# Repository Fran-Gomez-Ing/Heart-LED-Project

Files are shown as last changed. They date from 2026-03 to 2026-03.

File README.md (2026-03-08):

# Heart-LED-Project
Heart-shaped LED badge with integrated Li-ion battery charging system.

A self-initiated project to bridge the gap between theory and hardware. I designed, routed, and hand-assembled this PCB from scratch. It’s a portable, rechargeable system featuring:

Power: Portable system featuring a Li-ion battery with an integrated charging circuit (TP4056).

Architecture: Discrete LED array driven by an NE555 timer on a custom-shaped, double-layer PCB.

Toolchain: KiCad 9.0.

What I Learned:

End-to-End Workflow: Moved from theory to a physical product by managing the full cycle: footprints, BOM, and Gerber generation for manufacturing.

Component Selection: Mastered reading datasheets to select appropriate ICs, like the TP4056 for charging and the NE555 timer for logic.

DFA (Design for Assembly): Implemented HandSolder footprints with enlarged pads to ensure reliable manual assembly and easier debugging.

Power Integration: Gained practical experience with Li-ion battery management and USB power standards.

Possible Improvements:

Battery Safety: V1.0 focuses on the charging cycle. In the next iteration, I will add a DW01A protection IC and 8205A MOSFETs to prevent undervoltage (below 2.4V) and ensure battery longevity.

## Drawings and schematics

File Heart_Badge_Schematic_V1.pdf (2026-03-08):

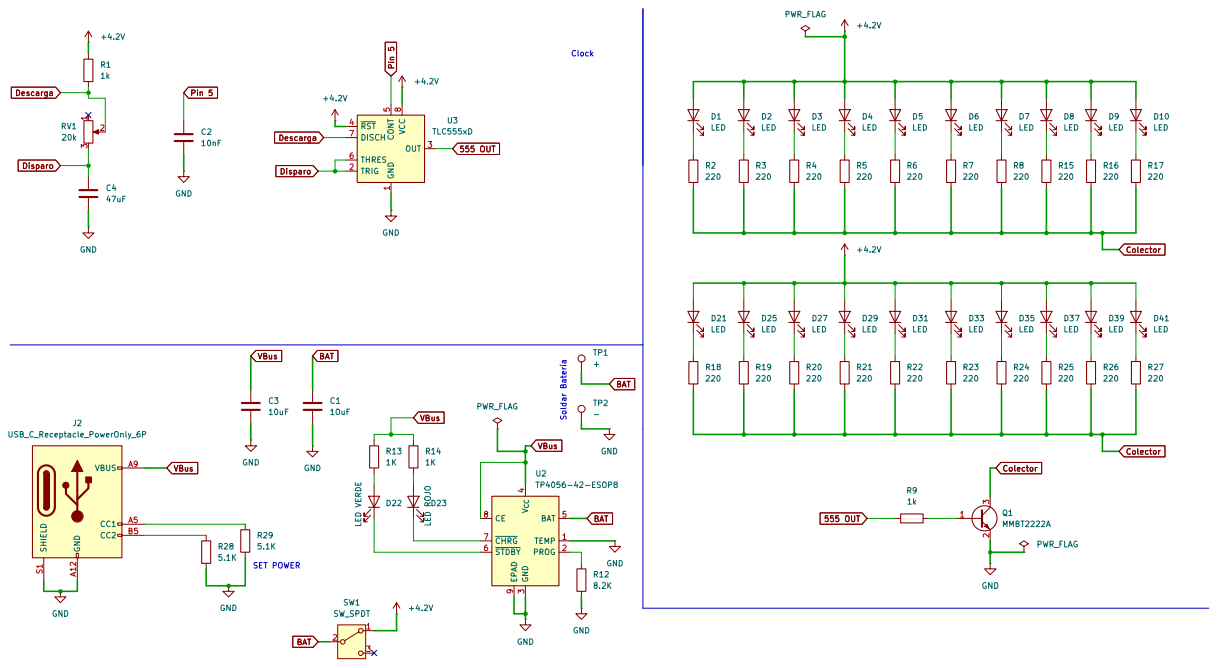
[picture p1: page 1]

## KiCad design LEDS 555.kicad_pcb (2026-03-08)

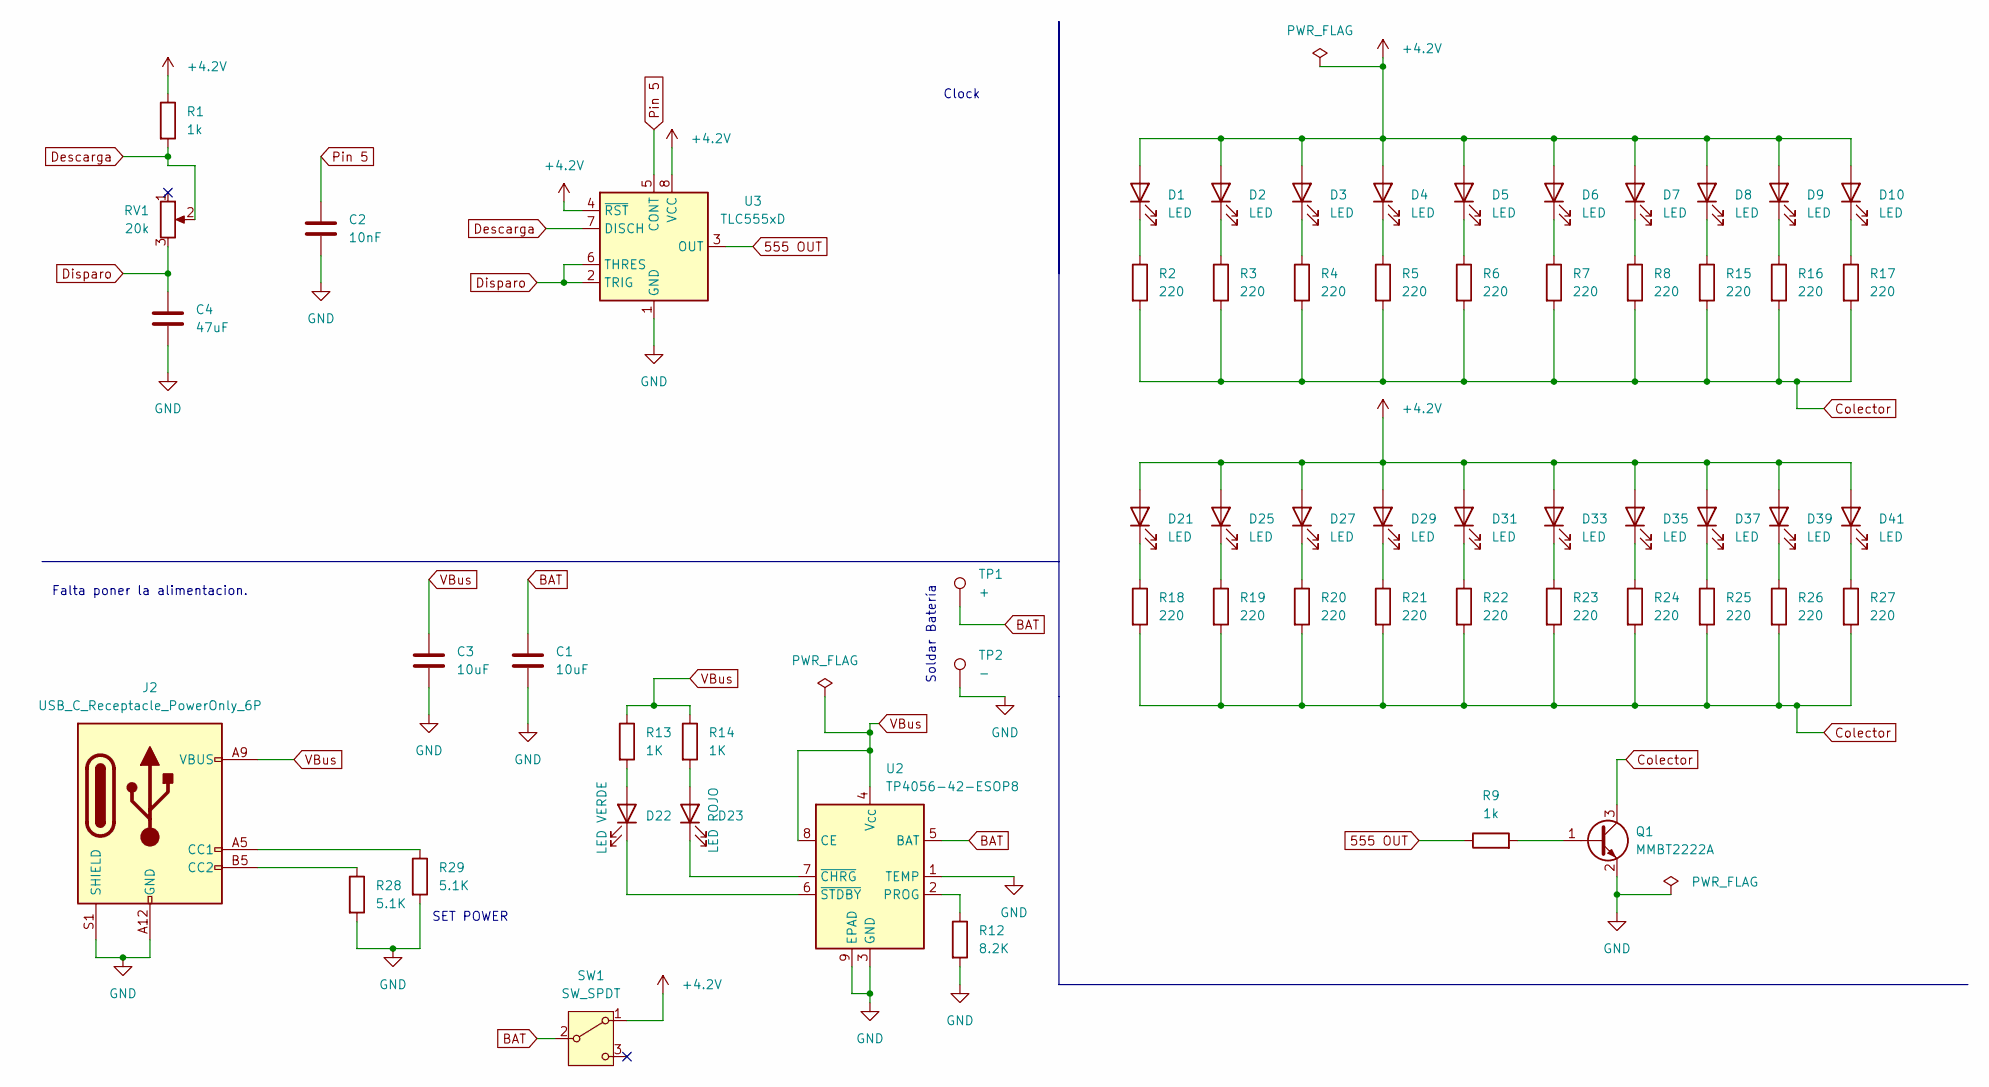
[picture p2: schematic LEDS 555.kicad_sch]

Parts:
C1, C3: 10uF; C_0805_2012Metric_Pad1.18x1.45mm_HandSolder; LCSC C440198
C2: 10nF; C_0805_2012Metric_Pad1.18x1.45mm_HandSolder; LCSC C83170
C4: 47uF; C_0805_2012Metric_Pad1.18x1.45mm_HandSolder; LCSC C16780
D1, D2, D3, D4, D5, D6, D7, D8, D9, D10, D21, D25, D27, D29, D31, D33, D35, D37, D39, D41: LED; LED_D3.0mm; LCSC C2895492
D22: LED VERDE; LED_0805_2012Metric_Pad1.15x1.40mm_HandSolder; LCSC C25170728
D23: LED ROJO; LED_0805_2012Metric_Pad1.15x1.40mm_HandSolder; LCSC C19171391
J2: USB_C_Receptacle_PowerOnly_6P; USB_C_Receptacle_GCT_USB4135-GF-A_6P_TopMnt_Horizontal; LCSC C5438410
Q1: MMBT2222A; SOT-23; LCSC C82460
R1, R9: 1k; R_0805_2012Metric_Pad1.20x1.40mm_HandSolder; LCSC C17513
R2, R3, R4, R5, R6, R7, R8, R15, R16, R17, R18, R19, R20, R21, R22, R23, R24, R25, R26, R27: 220; R_0805_2012Metric_Pad1.20x1.40mm_HandSolder; LCSC C17557
R12: 8.2K; R_0805_2012Metric_Pad1.20x1.40mm_HandSolder; LCSC C17828
R13, R14: 1K; R_0805_2012Metric_Pad1.20x1.40mm_HandSolder; LCSC C17513
R28, R29: 5.1K; R_0805_2012Metric_Pad1.20x1.40mm_HandSolder; LCSC C27834
RV1: 20k; Potentiometer_Alps_RK09K_Single_Vertical; LCSC C470290
SW1: SW_SPDT; SW_SPDT_PCM12; LCSC C221841
TP1: +; TestPoint_Pad_D2.0mm
TP2: -; TestPoint_Pad_D2.0mm
U2: TP4056-42-ESOP8; SOIC-8-1EP_3.9x4.9mm_P1.27mm_EP2.41x3.3mm_ThermalVias; LCSC C16581
U3: TLC555xD; SOIC-8_3.9x4.9mm_P1.27mm; LCSC C6986

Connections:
555 OUT: R9.1, U3.3 (OUT)
+4.2V: D1.2 (A), D2.2 (A), D3.2 (A), D4.2 (A), D5.2 (A), D6.2 (A), D7.2 (A), D8.2 (A), D9.2 (A), D10.2 (A), D21.2 (A), D25.2 (A), D27.2 (A), D29.2 (A), D31.2 (A), D33.2 (A), D35.2 (A), D37.2 (A), D39.2 (A), D41.2 (A), R1.1, SW1.1 (A), U3.4 (~RST), U3.8 (VCC)
BAT: C1.1, SW1.2 (B), TP1.1, U2.5 (BAT)
Colector: Q1.3 (C), R2.2, R3.2, R4.2, R5.2, R6.2, R7.2, R8.2, R15.2, R16.2, R17.2, R18.2, R19.2, R20.2, R21.2, R22.2, R23.2, R24.2, R25.2, R26.2, R27.2
Descarga: R1.2, RV1.2, U3.7 (DISCH)
Disparo: C4.1, RV1.3, U3.2 (TRIG), U3.6 (THRES)
GND: C1.2, C2.2, C3.2, C4.2, J2.A12 (GND), J2.B12 (GND), J2.S1 (SHIELD), Q1.2 (E), R12.2, R28.2, R29.2, TP2.1, U2.1 (TEMP), U2.3 (GND), U2.9 (EPAD), U3.1 (GND)
unnamed: D1.1 (K), R2.1
unnamed: D2.1 (K), R3.1
unnamed: D3.1 (K), R4.1
unnamed: D4.1 (K), R5.1
unnamed: D5.1 (K), R6.1
unnamed: D6.1 (K), R7.1
unnamed: D7.1 (K), R8.1
unnamed: D8.1 (K), R15.1
unnamed: D9.1 (K), R16.1
unnamed: D10.1 (K), R17.1
unnamed: D21.1 (K), R18.1
unnamed: D22.2 (A), R13.2
unnamed: D22.1 (K), U2.6 (~STDBY)
unnamed: D23.2 (A), R14.2
unnamed: D23.1 (K), U2.7 (~CHRG)
unnamed: D25.1 (K), R19.1
unnamed: D27.1 (K), R20.1
unnamed: D29.1 (K), R21.1
unnamed: D31.1 (K), R22.1
unnamed: D33.1 (K), R23.1
unnamed: D35.1 (K), R24.1
unnamed: D37.1 (K), R25.1
unnamed: D39.1 (K), R26.1
unnamed: D41.1 (K), R27.1
unnamed: J2.A5 (CC1), R29.1
unnamed: J2.B5 (CC2), R28.1
unnamed: Q1.1 (B), R9.2
unnamed: R12.1, U2.2 (PROG)
Pin 5: C2.1, U3.5 (CONT)
VBus: C3.1, J2.A9 (VBUS), J2.B9 (VBUS), R13.1, R14.1, U2.4 (V_{CC}), U2.8 (CE)

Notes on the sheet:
Clock
Soldar Batería
SET POWER
Falta poner la alimentacion.

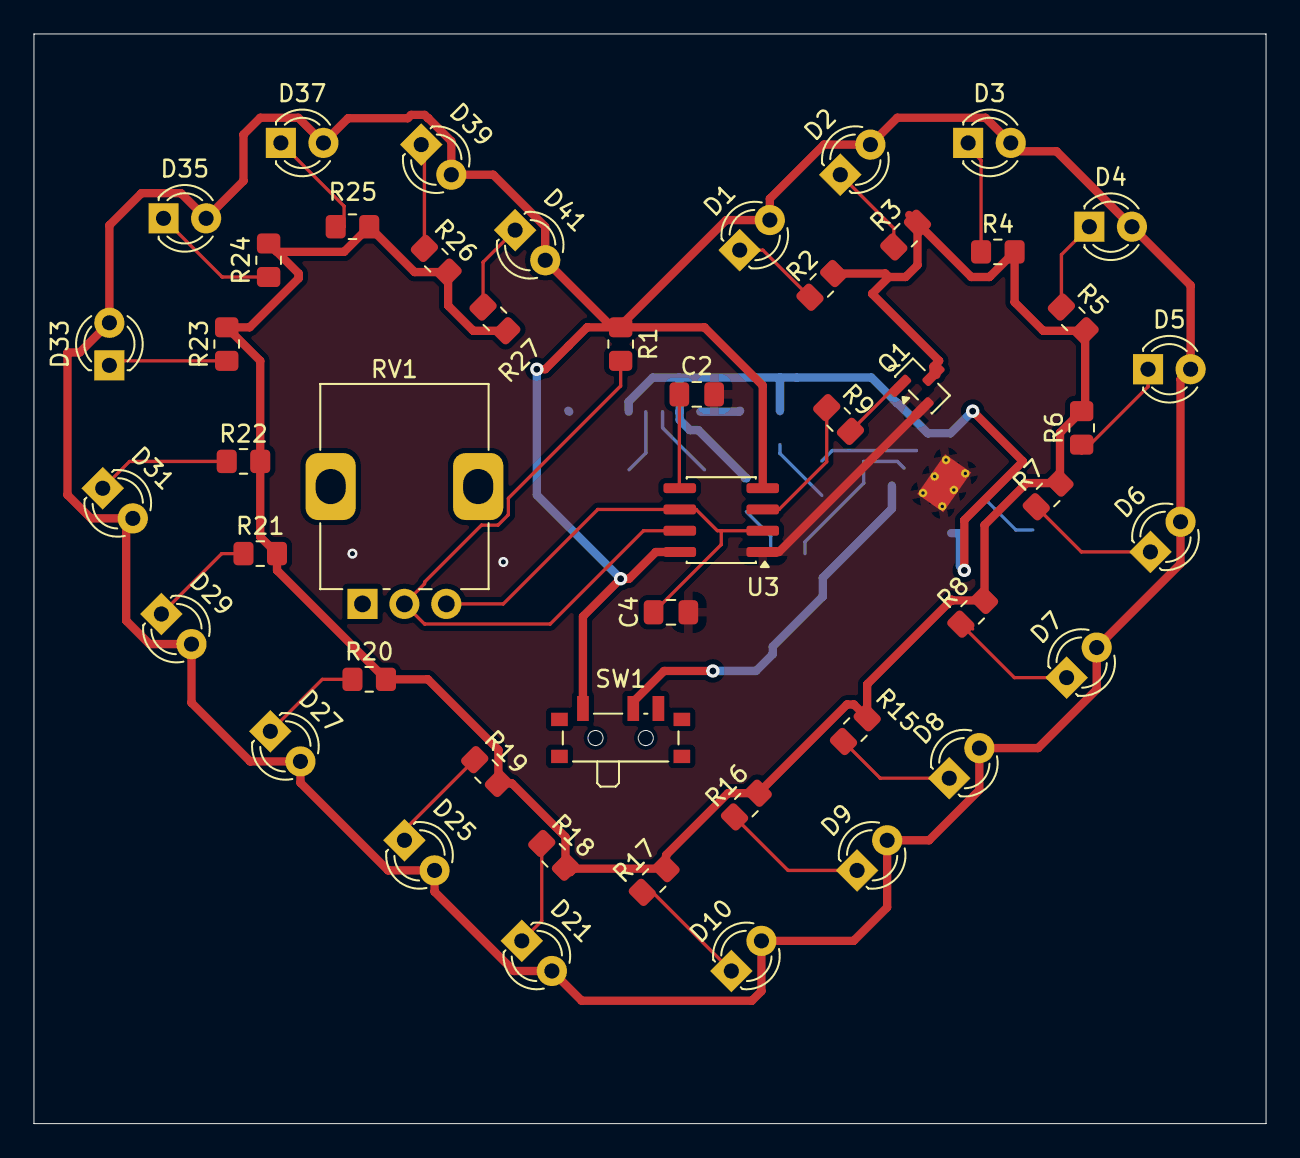
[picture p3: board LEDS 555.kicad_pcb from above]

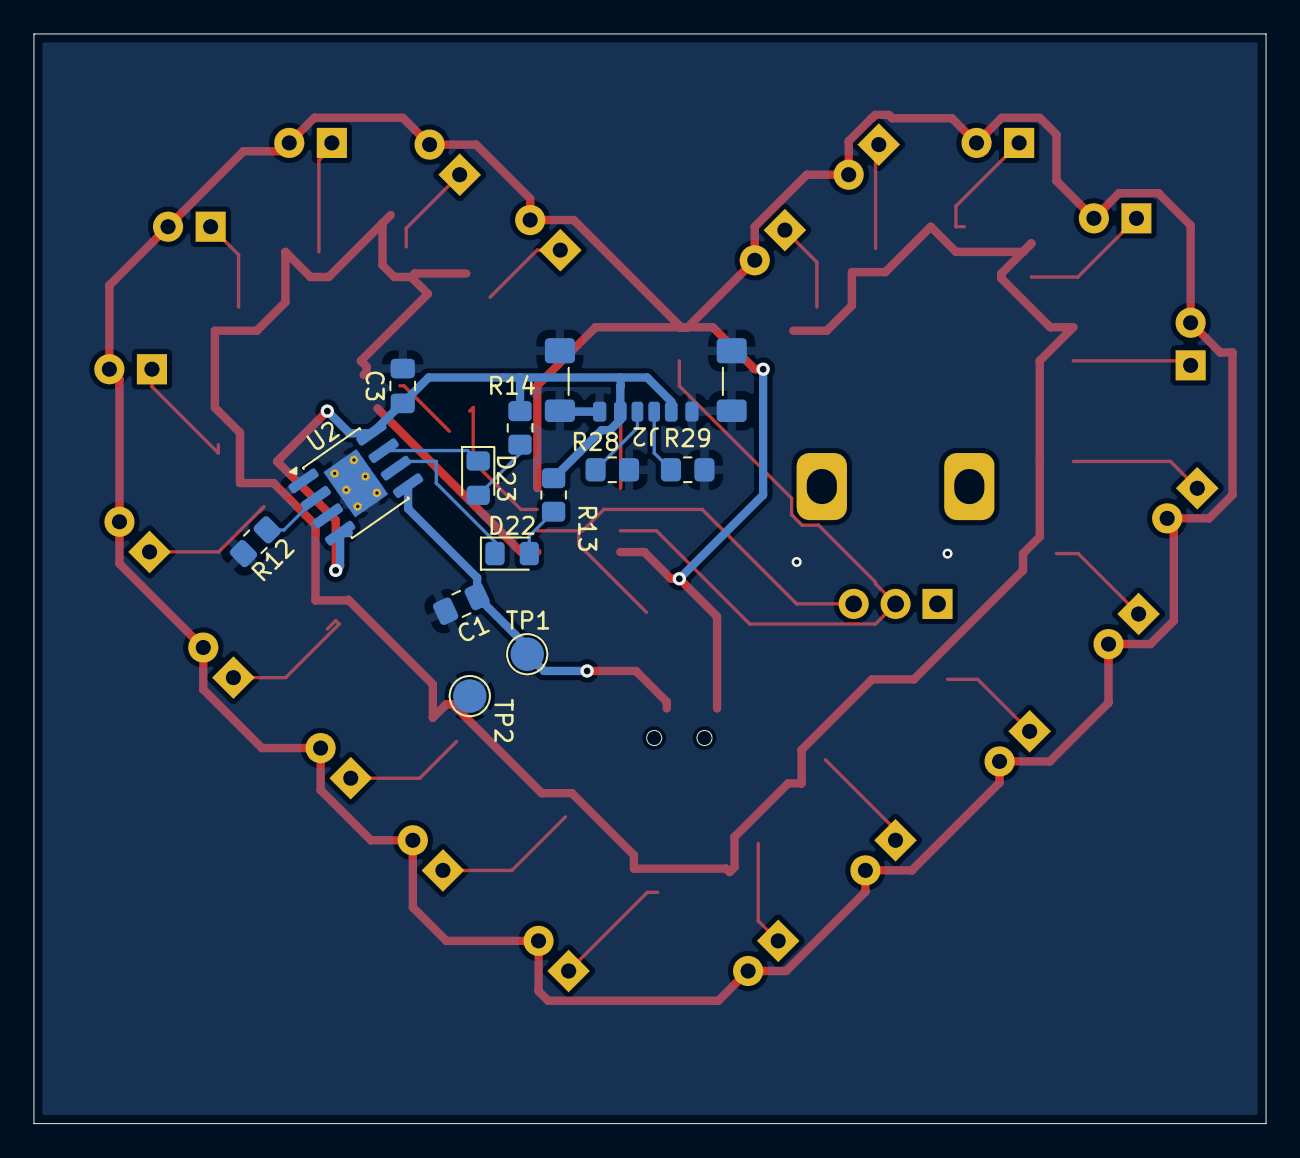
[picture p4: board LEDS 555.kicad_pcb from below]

Board: 2 copper layers, 73.5 x 65.0 mm, 61 parts (13 on the bottom side), 37 nets.
